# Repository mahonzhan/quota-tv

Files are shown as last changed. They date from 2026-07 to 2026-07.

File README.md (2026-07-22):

# QuotaTV — Claude + ChatGPT 订阅额度桌面显示器

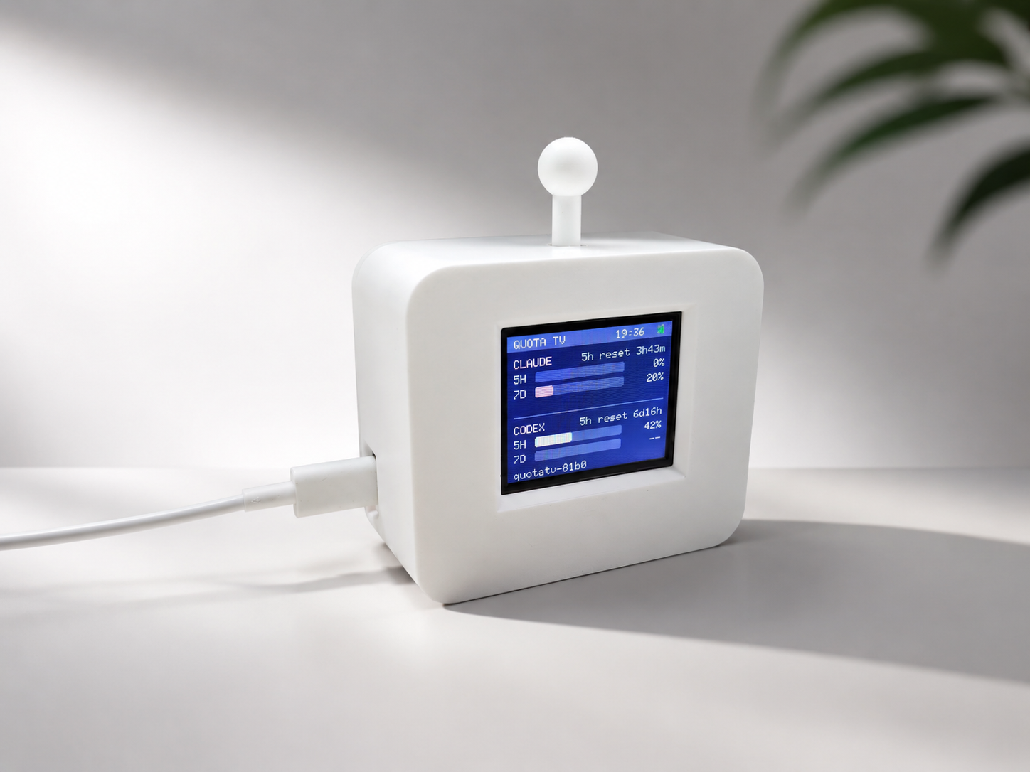
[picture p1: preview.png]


ESP32-C3 DevKitM-1 + 1.8" ST7735 的复古小电脑,单屏显示 Claude Code 与 ChatGPT(Codex) 的 5h/周额度使用率和重置倒计时,额度重置时蜂鸣提醒。设备直连两家接口,**不需要电脑常驻脚本**。

```
┌──────────────────────────────┐
│ QUOTA TV          14:32  ●   │
│ CLAUDE        5h reset 2h14m │
│  5H ██████████░░░░░░░   62%  │
│  7D ██████░░░░░░░░░░░   41%  │
│ ──────────────────────────── │
│ CODEX         5h reset 4h02m │
│  5H █████░░░░░░░░░░░░   30%  │
│  7D ████████████░░░░░   71%  │
│ 192.168.1.23                 │
└──────────────────────────────┘
```

## 1. 硬件与接线

| ST7735 屏 (8针) | ESP32-C3 DevKitM-1 |
|---|---|
| GND | GND |
| VCC | 3V3 |
| SCL / SCK | GPIO4 |
| SDA / MOSI | GPIO6 |
| RES / RST | GPIO10 |
| DC / A0 | GPIO5 |
| CS | GPIO7 |
| BLK / LED | GPIO3 |

| 蜂鸣器模块 (低电平触发) | DevKitM-1 |
|---|---|
| VCC | 3V3 (响声小可接 5V/VUSB) |
| GND | GND |
| I/O | GPIO1 |

> 避开了 C3 的 strapping 引脚 (GPIO2/8/9)。GPIO9 是板载 BOOT 键,固件里用作按钮。

## 2. 刷固件

```bash
pip install platformio
cd firmware
pio run -t upload        # USB 连接 DevKitM-1
pio device monitor       # 看日志 (115200)
```

### ST7735 变体调试(几乎必经步骤)

1.8" ST7735 有红标/绿标/黑标多种批次。本项目实测的蓝板 (丝印 1.8'TFT128*RGB*160) 为 **REDTAB + TFT_RGB**,已设为默认。其他批次若画面异常,改 `platformio.ini`:

- 偏移/花屏 → 把 `ST7735_REDTAB` 依次换成 `ST7735_BLACKTAB` / `ST7735_GREENTAB` / `ST7735_GREENTAB2` / `ST7735_GREENTAB3`
- 蓝橙互换 → `TFT_RGB_ORDER` 在 `TFT_RGB` / `TFT_BGR` 之间切换
- 方向反了 → `main.cpp` 里 `tft.setRotation(3)` 改成 `1`

## 3. 获取凭据

在装有 Claude Code 和 Codex CLI 的电脑上:

```bash
# Claude: 生成长期 OAuth token (推荐)
claude setup-token        # 输出 sk-ant-oat01-...

# Codex: 一键打印 access/refresh token
python tools/get_tokens.py
```

## 4. 配置设备

1. 首次上电自动进入配置模式;已配置的设备**运行中长按 BOOT 3 秒**(听到一声蜂鸣后松手)或 `curl -X POST http://<设备IP>/portal` 重新进入。注意**不要按住 BOOT 上电**——C3 会进串口下载模式导致黑屏(拔电重插即恢复)
2. 手机/电脑连接 `QuotaTV-xxxx` 热点,打开 `http://192.168.4.1`
3. 填 WiFi(2.4GHz)、Claude token、Codex access + refresh token,保存重启

运行后设备每 2 分钟刷新一次;按一下 BOOT 键立即刷新。浏览器访问 `http://<设备IP>/status` 可看 JSON 数据;`POST /reset` 清空配置。

## 5. 双工作模式

配置页可选两种模式:

**直连模式(默认)**:设备自己调两家接口,不依赖电脑。需在配置页填入 token。

**主机 Agent 模式**:token 不上设备,由电脑上的 `quota-agent`(Go 编写,单二进制零依赖)读取本机 Claude Code / Codex CLI 凭据,拉取额度后经局域网 HTTP 推送到设备(`POST /push`)。Codex token 由 CLI 自动续期,Agent 直接受益。代价是电脑关机后设备显示 stale。

### 设备发现(Agent 模式)

三层机制,按优先级:

1. **UDP 广播发现(主路径,不依赖 mDNS)**:Agent 向 18324 端口广播 `QUOTATV_DISCOVER?`,设备回 `{name, ip, mode}`。同网多台设备各有唯一名 `quotatv-xxxx`(MAC 后缀,屏幕底行与 IP 交替显示):发现多台时用 `-name quotatv-a1b2` 指定,或 `-all` 全部推送(数据只拉一次)
2. mDNS 兜底:每台设备注册 `quotatv-xxxx.local`
3. 手动指定:`-device http://192.168.x.x`(AP 隔离等广播不通的网络用这个)

### Agent 获取与运行

**推荐**:直接从 [Releases](https://github.com/mahonzhan/quota-tv/releases) 下载对应平台的 quota-agent(打 tag 后由 GitHub Actions 自动构建:Windows amd64 / macOS arm64+amd64 / Linux amd64)。

双击(或命令行)运行后**驻留系统托盘**(Windows 任务栏 / macOS 菜单栏 / Linux 状态区),托盘菜单提供:最近推送状态、立即推送、**开机自启开关**(写入各平台原生自启机制:注册表 Run / LaunchAgent / autostart desktop)、退出。

托盘直接显示额度:**macOS** 菜单栏图标旁显示文字 `C62/41 G30/71`(Claude/Codex 的 5h/7d 已用%);**Windows/Linux** 托盘不支持文字,数字直接渲染进图标——上行橙色为 Claude 5h、下行白色为 Codex 5h,悬停 tooltip 看完整数据。

**macOS 下载 `.app.zip`**(而非裸二进制):解压后双击即驻留菜单栏,不开终端、不占 Dock。首次打开因未签名会被 Gatekeeper 拦截,右键 → 打开 → 再点打开即可。裸二进制版供命令行/launchd 场景使用。

命令行参数(托盘模式同样生效):

```bash
quota-agent                  # 托盘常驻, 自动发现设备, 每 2 分钟推送
quota-agent -once            # 调试: 发现设备并推一次后退出
quota-agent -nogui           # 无托盘纯命令行 (服务器/systemd 场景)
quota-agent -name quotatv-a1b2   # 多设备时指定
quota-agent -all             # 多设备全部推送
quota-agent -device http://192.168.1.50   # 广播不通时手动指定
```

自己编译(`cd tools/quota-agent`):

```bash
# Windows — 必须加 -H windowsgui, 否则 exe 启动会弹黑色控制台窗口
go build -ldflags "-s -w -H windowsgui" -o quota-agent.exe

# macOS / Linux
go build -ldflags "-s -w" -o quota-agent
```

注意:`-H windowsgui` 的 GUI 版没有控制台,`log` 输出不可见;Windows 上调试(看发现/推送日志)时用不带该参数的构建跑 `quota-agent -once`。macOS 版依赖 cgo,需在 mac 上编译(Releases 里的由 CI 的 macos runner 构建)。

exe 文件图标:仓库已提交 `rsrc_windows_amd64.syso`(由 `icon.ico` 经 [akavel/rsrc](https://github.com/akavel/rsrc) 生成),`go build` 自动链接,无需额外操作;改图标时重新生成该文件即可(`go run github.com/akavel/rsrc@latest -ico icon.ico -o rsrc_windows_amd64.syso`)。macOS 裸二进制没有文件图标概念,要图标需打包成 .app bundle(未做,菜单栏图标不受影响)。

### 发布流程 (维护者)

```bash
git tag v1.0.0 && git push origin v1.0.0
```

`.github/workflows/release.yml` 会在三平台 runner 上构建 4 个二进制并自动创建 GitHub Release。

## 6. 数据来源(与风险)

- **Claude**:发送 `max_tokens=1` 的最小请求,从响应头 `anthropic-ratelimit-unified-5h/7d-utilization`(0~1)和 `-reset`(epoch)读取。每次探测消耗几个 token,量级可忽略。
- **Codex**:`GET chatgpt.com/backend-api/wham/usage`,零消耗;access token 过期时自动用 refresh token 到 `auth.openai.com` 续期并存入 NVS。
- 两个都是**非官方接口**,可能随时变化。解析已尽量写得宽容,失败时屏幕显示错误码,串口有原始响应片段可排查。
- 若设备端 refresh 与电脑上 Codex CLI 的凭据互相顶掉(表现为某一边频繁要求重新登录),改为定期从电脑重新粘贴 access token、refresh token 留空。
- 固件对 TLS 用 `setInsecure()`(不校验证书链)。家庭内网风险可接受;介意的话把各域名根证书写进固件。

## 6. 蜂鸣逻辑

- 任一窗口利用率相比上次骤降 ≥25 个百分点,或跨过 reset 时间点 → 蜂鸣(Claude 两声,Codex 三声)
- 静音时段 23:00–08:00(`config.h` 可改)
- 开机就绪一声短鸣

## 7. 外壳打印 (case/) — Claude bot 橙色机器人造型

用**橙色 PLA**打印(Claude 品牌色约 #D97757),效果图见 `case/assembly_preview.png`。

适配硬件:1.8" TFT128×RGB×160 蓝板屏 + **合宙 Core-ESP32C3** + 三针立式有源蜂鸣器模块,飞线直焊。

- `body.stl` — 机器人头主壳(74×64×30, 大圆角):前脸朝下打印,免支撑;顶部天线插孔,右侧壁后缘 USB-C 出线缺口
- `antenna.stl` — 球头天线:竖直打印,杆 φ5.6 插入 φ6 孔,过松点胶
- `back.stl` — 后盖:平放打印;含 **BOOT/RST 两个按钮孔**、蜂鸣孔、散热缝、唇部 USB 缺口
- `button_plunger_x2.stl` — 按钮顶杆,打印 2 个:蘑菇头朝内放入孔中,再贴板,即可从壳外按 BOOT/RST
- `stand.stl` — 12° 仰角底座,带两只小脚趾
- 装配:屏幕贴入前脸内侧定位框 → 顶杆入孔 → **合宙板元件面朝后盖**、USB-C 对准 -x 缺口方向,按钮对准顶杆后用双面胶/热熔胶贴在后盖内侧 → 蜂鸣器贴出音孔附近 → 飞线焊好插上后盖 → 插天线 → 卡入底座
- 源文件 `gen_case.py`(STL 以它为准):打印前量三个尺寸并改参数重新生成——屏模块 PCB 宽高(`SCR_PCB_W/H`)、合宙板 USB 端边缘到按钮中心距(`BTN_FROM_USB`)、两按钮中心距(`BTN_GAP`)

## 8. 安全提醒

token 等同账号使用权,只存在设备 NVS 里,不要把配置好的设备借人;闲鱼出手前 `POST /reset` 或重刷固件。

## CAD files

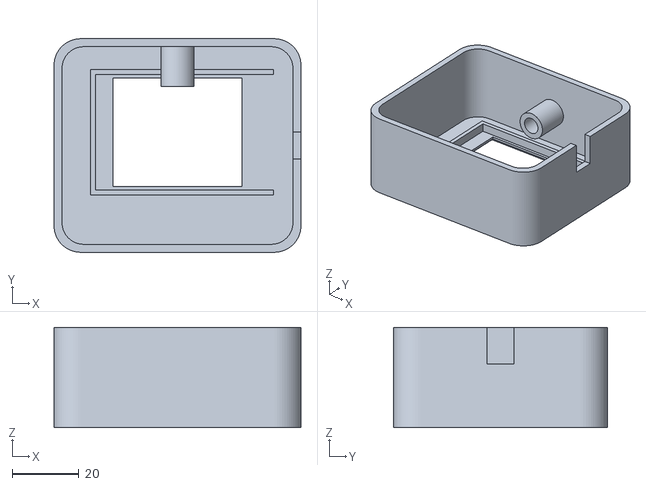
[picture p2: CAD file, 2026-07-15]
case/body.stl
74.0 x 64.0 x 30.0

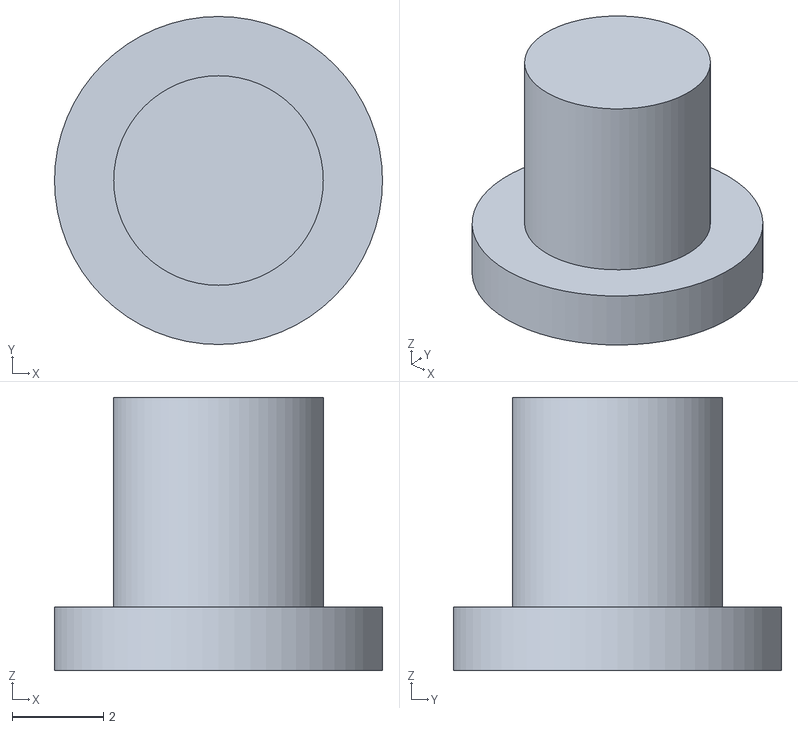
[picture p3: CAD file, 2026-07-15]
case/button_plunger_x2.stl
7.20 x 7.20 x 6.00

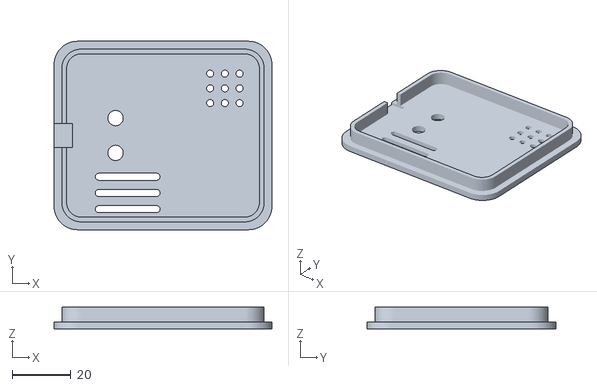
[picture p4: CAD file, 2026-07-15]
case/back.stl
74.0 x 64.0 x 7.40

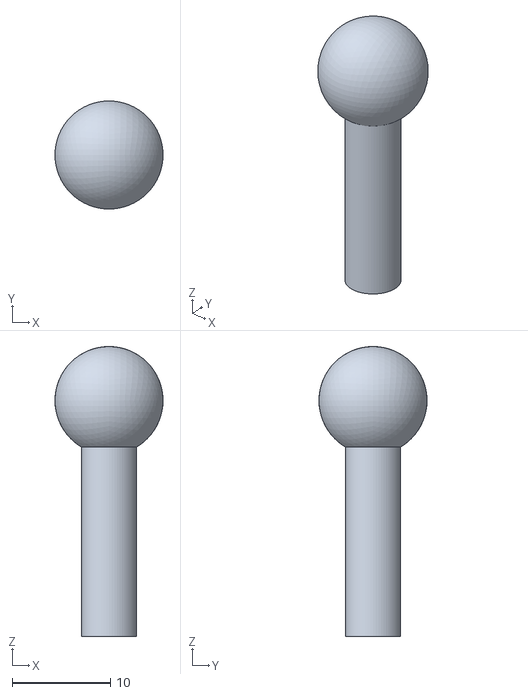
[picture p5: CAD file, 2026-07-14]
case/antenna.stl
11.0 x 11.0 x 29.5

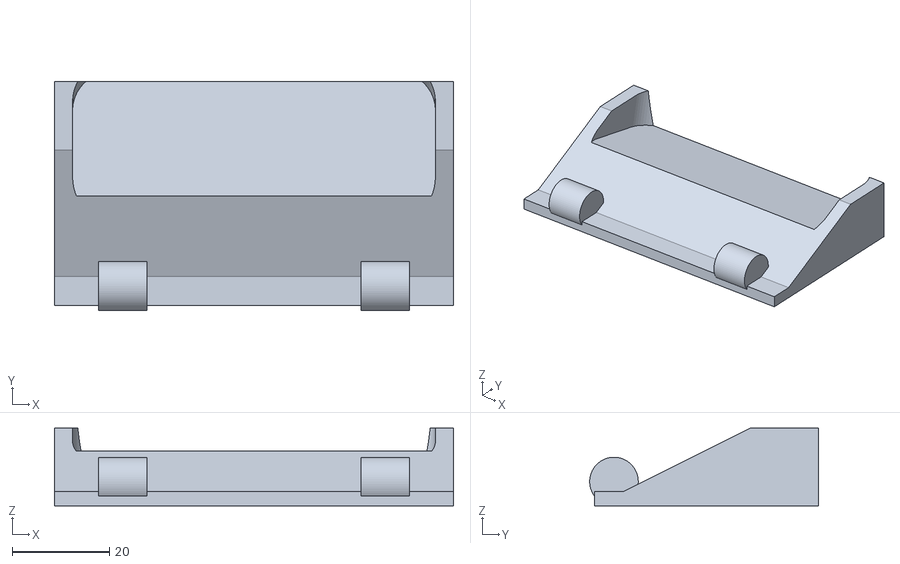
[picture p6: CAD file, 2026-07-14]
case/stand.stl
82.0 x 47.0 x 16.0

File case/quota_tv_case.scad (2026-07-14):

// ============================================================
// QuotaTV 外壳 — Claude bot 橙色机器人造型 (参数化, 与 gen_case.py 等价)
// 部件: body / back / antenna / stand    橙色 PLA (#D97757)
// 注意: 发货 STL 由 gen_case.py 生成; 本文件供 OpenSCAD 用户改参
// ============================================================

part = "all"; // [all, body, back, antenna, stand]

/* ---- 屏幕 1.8" ST7735 ---- */
scr_view_w = 36.5;  scr_view_h = 29.5;   // 可视区开窗
scr_pcb_w  = 58;    scr_pcb_h  = 35;     // 模块 PCB, 按实物量!
scr_y_off  = 4;

/* ---- 主体 ---- */
wall = 2.4;
body_w = 74; body_h = 64; body_d = 30;
corner = 8;                              // 大圆角机器人头

/* ---- 后盖 ---- */
lip_d = 5; lip_clear = 0.28;
usb_w = 13; usb_h = 8; usb_z = 10;

/* ---- 天线 ---- */
ant_hole_d = 6; ant_stem_d = 5.6;
ant_stem_h = 16; ant_ball_d = 11;

/* ---- 底座 ---- */
tilt = 12; stand_d = 46; stand_lip = 7;

$fn = 64;

module rbox(w, h, d, r) {
  translate([w/2, h/2, 0]) linear_extrude(d) offset(r = r) square([w - 2*r, h - 2*r], center = true);
}

module body() {
  difference() {
    union() {
      difference() {
        rbox(body_w, body_h, body_d, corner);
        translate([wall, wall, wall]) rbox(body_w - 2*wall, body_h - 2*wall, body_d, corner - 1.5);
      }
      // 天线凸台
      translate([body_w/2, body_h - wall + 0.01, body_d/2])
        rotate([90, 0, 0]) cylinder(h = 12, d = 10);
      // 屏幕定位框
      translate([body_w/2, body_h/2 + scr_y_off, wall]) difference() {
        translate([-scr_pcb_w/2 - 1.8, -scr_pcb_h/2 - 1.8, 0]) cube([scr_pcb_w + 3.6, scr_pcb_h + 3.6, 3]);
        translate([-scr_pcb_w/2 - 0.3, -scr_pcb_h/2 - 0.3, -0.5]) cube([scr_pcb_w + 0.6, scr_pcb_h + 0.6, 4]);
      }
    }
    // 屏幕开窗 + 外侧倒角
    translate([body_w/2, body_h/2 + scr_y_off, 0]) {
      translate([-scr_view_w/2, -scr_view_h/2, -0.5]) cube([scr_view_w, scr_view_h, wall + 1]);
      hull() {
        translate([-scr_view_w/2 - 1.6, -scr_view_h/2 - 1.6, -0.5]) cube([scr_view_w + 3.2, scr_view_h + 3.2, 0.5]);
        translate([-scr_view_w/2, -scr_view_h/2, wall - 0.8]) cube([scr_view_w, scr_view_h, 0.1]);
      }
    }
    // 天线通孔
    translate([body_w/2, body_h + 0.01, body_d/2]) rotate([90, 0, 0]) cylinder(h = wall + 12.5, d = ant_hole_d);
  }
}

module back() {
  difference() {
    union() {
      rbox(body_w, body_h, wall, corner);
      translate([wall + lip_clear, wall + lip_clear, wall]) difference() {
        rbox(body_w - 2*wall - 2*lip_clear, body_h - 2*wall - 2*lip_clear, lip_d, corner - 1.5);
        translate([1.6, 1.6, -0.5])
          rbox(body_w - 2*wall - 2*lip_clear - 3.2, body_h - 2*wall - 2*lip_clear - 3.2, lip_d + 1, corner - 3);
      }
    }
    translate([body_w/2 - usb_w/2, usb_z - usb_h/2, -0.5]) cube([usb_w, usb_h, wall + lip_d + 1]);
    for (dx = [-5, 0, 5], dy = [-5, 0, 5])
      translate([body_w - 16 + dx, body_h - 16 + dy, -0.5]) cylinder(h = wall + 2, d = 2.4);
    for (i = [0:3]) translate([14, body_h/2 - 8 + i*7, -0.5]) rbox(22, 2.4, wall + 2, 1.2);
  }
}

module antenna() {
  cylinder(h = 8 + ant_stem_h, d = ant_stem_d);
  translate([0, 0, 8 + ant_stem_h]) sphere(d = ant_ball_d);
}

module stand() {
  w = body_w + 8;
  difference() {
    translate([w, 0, 0]) rotate([0, -90, 0]) linear_extrude(w)
      polygon([[0,0],[3,0],[3,6],[16,stand_d-14],[16,stand_d],[0,stand_d]]); // (z,y) 轮廓
    // 主体卡槽
    translate([w/2 - 4, stand_d - 13, 16 - stand_lip]) rotate([-tilt, 0, 0])
      translate([-(body_w/2 + lip_clear) + 4, -(body_d/2 + lip_clear), 0])
        rbox(body_w + 2*lip_clear, body_d + 2*lip_clear, body_h, corner);
  }
  for (sx = [14, w - 14]) translate([sx - 5, 4, 5]) rotate([0, 90, 0]) cylinder(h = 10, r = 5);
}

if (part == "body"    || part == "all") body();
if (part == "back"    || part == "all") translate([body_w + 12, 0, 0]) back();
if (part == "antenna" || part == "all") translate([-16, 20, 0]) antenna();
if (part == "stand"   || part == "all") translate([0, body_h + 14, 0]) stand();

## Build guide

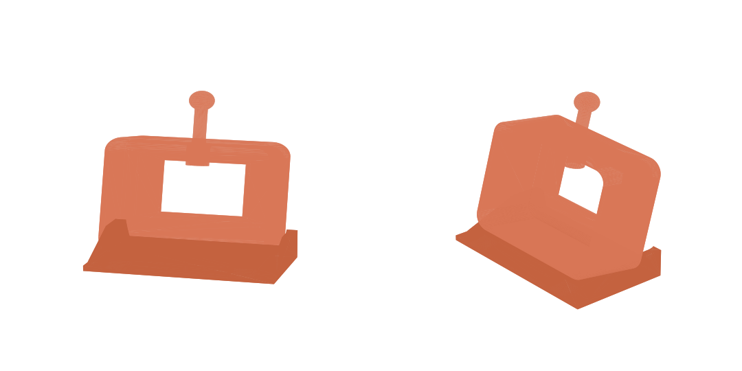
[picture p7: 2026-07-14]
case/assembly_preview.png

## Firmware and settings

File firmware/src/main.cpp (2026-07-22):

// ============================================================
// QuotaTV — Claude Code + ChatGPT(Codex) 订阅额度桌面显示器
// 硬件: ESP32-C3 DevKitM-1 + 1.8" ST7735 (128x160) + 低电平有源蜂鸣器
// 功能: 单屏显示两家 5h/周额度利用率 + 重置倒计时, 额度重置时蜂鸣提醒
// ============================================================

#include <Arduino.h>
#include <WiFi.h>
#include <WiFiClientSecure.h>
#include <HTTPClient.h>
#include <WebServer.h>
#include <DNSServer.h>
#include <ESPmDNS.h>
#include <WiFiUdp.h>
#include <Preferences.h>
#include <ArduinoJson.h>
#include <TFT_eSPI.h>
#include <time.h>
#include "config.h"

// ---------------- 全局 ----------------
TFT_eSPI    tft;
TFT_eSprite canvas(&tft);          // 全屏离屏缓冲, 防闪烁 (160x128x2 = 40KB)
Preferences prefs;
WebServer   server(80);
DNSServer   dns;
WiFiUDP     udp;                   // UDP 发现响应 (不依赖 mDNS)
String      devName;               // quotatv-xxxx (MAC 后缀, 全网唯一)
#define DISCOVERY_PORT 18324

struct Cfg {
  String ssid, pass;
  String mode;                     // "direct" 直连 (默认) / "agent" 主机推送
  String claudeToken;              // sk-ant-oat01-... (claude setup-token)
  String codexAccess, codexRefresh;
} cfg;

struct WindowData {
  float  usedPct    = -1;          // 0~100, <0 = 无数据
  time_t resetAt    = 0;           // unix epoch, 0 = 未知
};
uint32_t staleAfterMs = STALE_AFTER_MS;   // agent 模式下由推送帧 interval 动态覆盖
struct ProviderData {
  WindowData session, weekly;      // 5h / 7d
  uint32_t lastOkMs   = 0;
  String   lastErr;
  bool fresh() const { return lastOkMs && (millis() - lastOkMs) < staleAfterMs; }
  uint32_t ageMin() const { return lastOkMs ? (millis() - lastOkMs) / 60000UL : 0; }
};
ProviderData claudeData, codexData;

bool portalMode = false;
uint32_t lastPollMs = 0;
bool firstPollDone = false;

// ---------------- 颜色 ----------------
#define C_BG        0x0000                       // 黑
#define C_HEADER    0x39C7                       // 深灰
#define C_TEXT      0xEF7D                       // 近白
#define C_DIM       0x8410                       // 中灰
#define C_CLAUDE    0xD3AB                       // Claude 品牌橙红 #D97757 精确转换
#define C_CODEX     0xFFFF                       // Codex 白
#define C_BAR_BG    0x2124                       // bar 底槽
#define C_WARN      0xFDA0                       // 黄
#define C_DANGER    0xF9E7                       // 红

// ============================================================
// 蜂鸣器 (低电平触发)
// ============================================================
static void buzzInit() {
  pinMode(PIN_BUZZER, OUTPUT);
  digitalWrite(PIN_BUZZER, HIGH);  // 立刻拉高静音
}
static bool inQuietHours() {
  struct tm t;
  if (!getLocalTime(&t, 50)) return false;
  int h = t.tm_hour;
  if (QUIET_HOUR_START > QUIET_HOUR_END)       // 跨午夜, 如 23~8
    return h >= QUIET_HOUR_START || h < QUIET_HOUR_END;
  return h >= QUIET_HOUR_START && h < QUIET_HOUR_END;
}
static void beep(uint8_t n, uint16_t onMs = 90, uint16_t offMs = 90) {
  for (uint8_t i = 0; i < n; i++) {
    digitalWrite(PIN_BUZZER, LOW);  delay(onMs);
    digitalWrite(PIN_BUZZER, HIGH); delay(offMs);
  }
}

// ============================================================
// 小工具
// ============================================================
static String fmtCountdown(time_t resetAt) {
  time_t now = time(nullptr);
  if (resetAt <= 0 || now < 1600000000 || resetAt <= now) return "";
  long s = resetAt - now;
  char buf[16];
  if (s >= 86400)      snprintf(buf, sizeof(buf), "%ldd%02ldh", s / 86400, (s % 86400) / 3600);
  else if (s >= 3600)  snprintf(buf, sizeof(buf), "%ldh%02ldm", s / 3600, (s % 3600) / 60);
  else                 snprintf(buf, sizeof(buf), "%ldm", s / 60);
  return String(buf);
}

// base64url 解码 (用于解析 JWT exp)
static String b64urlDecode(const String& in) {
  String s = in;
  s.replace('-', '+'); s.replace('_', '/');
  while (s.length() % 4) s += '=';
  static const char* T = "ABCDEFGHIJKLMNOPQRSTUVWXYZabcdefghijklmnopqrstuvwxyz0123456789+/";
  String out; out.reserve(s.length() * 3 / 4);
  int val = 0, bits = 0;
  for (size_t i = 0; i < s.length(); i++) {
    char c = s[i];
    if (c == '=') break;
    const char* p = strchr(T, c);
    if (!p) continue;
    val = (val << 6) | (p - T);
    bits += 6;
    if (bits >= 8) { bits -= 8; out += (char)((val >> bits) & 0xFF); }
  }
  return out;
}
static time_t jwtExp(const String& jwt) {
  int p1 = jwt.indexOf('.'), p2 = jwt.indexOf('.', p1 + 1);
  if (p1 < 0 || p2 < 0) return 0;
  String payload = b64urlDecode(jwt.substring(p1 + 1, p2));
  JsonDocument doc;
  if (deserializeJson(doc, payload)) return 0;
  return (time_t)(doc["exp"] | 0UL);
}

// ============================================================
// 重置检测 + 蜂鸣
// ============================================================
static void checkReset(const char* name, WindowData& prev, const WindowData& fresh_, uint8_t beeps) {
  bool wasValid = prev.usedPct >= 0;
  bool dropped  = wasValid && fresh_.usedPct >= 0 &&
                  (prev.usedPct - fresh_.usedPct) >= RESET_DROP_THRESHOLD;
  bool resetPassed = prev.resetAt > 0 && fresh_.resetAt > prev.resetAt &&
                     time(nullptr) >= prev.resetAt && wasValid && prev.usedPct >= 20;
  if (dropped || resetPassed) {
    Serial.printf("[beep] %s reset: %.0f%% -> %.0f%%\n", name, prev.usedPct, fresh_.usedPct);
    if (!inQuietHours()) beep(beeps);
  }
}

// ============================================================
// Claude: 最小请求, 读 anthropic-ratelimit-unified-* 响应头
// ============================================================
static bool fetchClaude() {
  if (cfg.claudeToken.isEmpty()) { claudeData.lastErr = "no token"; return false; }
  WiFiClientSecure client;
  client.setInsecure();                      // 简化: 不校验证书 (README 有说明)
  HTTPClient http;
  http.setTimeout(HTTP_TIMEOUT_MS);
  if (!http.begin(client, String("https://") + CLAUDE_API_HOST + CLAUDE_API_PATH)) {
    claudeData.lastErr = "begin fail"; return false;
  }
  const char* keys[] = {
    "anthropic-ratelimit-unified-5h-utilization",
    "anthropic-ratelimit-unified-7d-utilization",
    "anthropic-ratelimit-unified-5h-reset",
    "anthropic-ratelimit-unified-7d-reset",
  };
  http.collectHeaders(keys, 4);
  http.addHeader("Content-Type", "application/json");
  http.addHeader("Authorization", "Bearer " + cfg.claudeToken);
  http.addHeader("anthropic-version", "2023-06-01");
  http.addHeader("anthropic-beta", "oauth-2025-04-20");
  String body = String("{\"model\":\"") + CLAUDE_PROBE_MODEL +
                "\",\"max_tokens\":1,\"messages\":[{\"role\":\"user\",\"content\":\"hi\"}]}";
  int code = http.POST(body);
  String u5 = http.header(keys[0]), u7 = http.header(keys[1]);
  String r5 = http.header(keys[2]), r7 = http.header(keys[3]);
  http.end();

  if (u5.isEmpty() && u7.isEmpty()) {
    claudeData.lastErr = "HTTP " + String(code);
    Serial.printf("[claude] no ratelimit headers, code=%d\n", code);
    return false;
  }
  WindowData s, w;
  if (!u5.isEmpty()) s.usedPct = u5.toFloat() * 100.0f;
  if (!u7.isEmpty()) w.usedPct = u7.toFloat() * 100.0f;
  // reset 头可能是 unix epoch 或 RFC3339, 只处理纯数字情况
  if (r5.length() && r5[0] >= '0' && r5[0] <= '9' && r5.indexOf('-') < 0) s.resetAt = (time_t)strtoul(r5.c_str(), nullptr, 10);
  if (r7.length() && r7[0] >= '0' && r7[0] <= '9' && r7.indexOf('-') < 0) w.resetAt = (time_t)strtoul(r7.c_str(), nullptr, 10);

  checkReset("claude-5h", claudeData.session, s, 2);
  checkReset("claude-7d", claudeData.weekly,  w, 2);
  claudeData.session = s; claudeData.weekly = w;
  claudeData.lastOkMs = millis(); claudeData.lastErr = "";
  Serial.printf("[claude] 5h=%.1f%% 7d=%.1f%%\n", s.usedPct, w.usedPct);
  return true;
}

// ============================================================
// Codex: GET wham/usage, 必要时用 refresh token 刷新
// ============================================================
static bool codexRefreshToken() {
  if (cfg.codexRefresh.isEmpty()) return false;
  WiFiClientSecure client; client.setInsecure();
  HTTPClient http;
  http.setTimeout(HTTP_TIMEOUT_MS);
  if (!http.begin(client, OPENAI_TOKEN_URL)) return false;
  http.addHeader("Content-Type", "application/json");
  JsonDocument req;
  req["client_id"]     = CODEX_CLIENT_ID;
  req["grant_type"]    = "refresh_token";
  req["refresh_token"] = cfg.codexRefresh;
  req["scope"]         = "openid profile email";
  String body; serializeJson(req, body);
  int code = http.POST(body);
  if (code != 200) { http.end(); Serial.printf("[codex] refresh fail %d\n", code); return false; }
  JsonDocument doc;
  DeserializationError e = deserializeJson(doc, http.getStream());
  http.end();
  if (e) return false;
  const char* at = doc["access_token"];
  const char* rt = doc["refresh_token"];
  if (!at) return false;
  cfg.codexAccess = at;
  if (rt && strlen(rt)) cfg.codexRefresh = rt;
  prefs.begin("quotatv", false);
  prefs.putString("cx_at", cfg.codexAccess);
  prefs.putString("cx_rt", cfg.codexRefresh);
  prefs.end();
  Serial.println("[codex] token refreshed");
  return true;
}

// 从 wham/usage 的 window 对象里尽量兼容地取值
static void parseCodexWindow(JsonVariantConst w, WindowData& out) {
  if (w.isNull()) return;
  if (w["used_percent"].is<float>())        out.usedPct = w["used_percent"].as<float>();
  else if (w["usage_percent"].is<float>())  out.usedPct = w["usage_percent"].as<float>();
  else if (w["used"].is<float>())           out.usedPct = w["used"].as<float>();
  time_t now = time(nullptr);
  if (w["resets_at"].is<long long>())            out.resetAt = (time_t)w["resets_at"].as<long long>();
  else if (w["reset_at"].is<long long>())        out.resetAt = (time_t)w["reset_at"].as<long long>();
  else if (w["resets_in_seconds"].is<long>())    out.resetAt = now + w["resets_in_seconds"].as<long>();
  else if (w["reset_after_seconds"].is<long>())  out.resetAt = now + w["reset_after_seconds"].as<long>();
  if (out.resetAt > 4102444800LL) out.resetAt /= 1000;   // 毫秒时间戳兜底
}

static bool fetchCodex() {
  if (cfg.codexAccess.isEmpty()) { codexData.lastErr = "no token"; return false; }
  // 到期前主动刷新
  time_t exp = jwtExp(cfg.codexAccess);
  time_t now = time(nullptr);
  if (exp > 0 && now > 1600000000 && exp - now < (time_t)CODEX_REFRESH_MARGIN_S) codexRefreshToken();

  for (int attempt = 0; attempt < 2; attempt++) {
    WiFiClientSecure client; client.setInsecure();
    HTTPClient http;
    http.setTimeout(HTTP_TIMEOUT_MS);
    if (!http.begin(client, CODEX_USAGE_URL)) { codexData.lastErr = "begin fail"; return false; }
    http.addHeader("Authorization", "Bearer " + cfg.codexAccess);
    http.addHeader("Accept", "application/json");
    http.addHeader("User-Agent", "QuotaTV/1.0");
    int code = http.GET();
    if (code == 401 && attempt == 0) {           // 过期 → 刷新重试
      http.end();
      if (!codexRefreshToken()) { codexData.lastErr = "401 refresh fail"; return false; }
      continue;
    }
    if (code != 200) { http.end(); codexData.lastErr = "HTTP " + String(code); return false; }
    JsonDocument doc;
    DeserializationError e = deserializeJson(doc, http.getStream());
    http.end();
    if (e) { codexData.lastErr = "json err"; return false; }

    JsonVariantConst rl = doc["rate_limit"];
    if (rl.isNull()) rl = doc["rate_limits"];
    WindowData s, w;
    parseCodexWindow(rl["primary_window"],   s);
    parseCodexWindow(rl["secondary_window"], w);
    if (s.usedPct < 0 && w.usedPct < 0) {
      // 结构不认识: 打印首 300 字符方便排查
      String dump; serializeJson(doc, dump);
      Serial.println("[codex] unknown shape: " + dump.substring(0, 300));
      codexData.lastErr = "parse shape";
      return false;
    }
    checkReset("codex-5h", codexData.session, s, 3);
    checkReset("codex-7d", codexData.weekly,  w, 3);
    codexData.session = s; codexData.weekly = w;
    codexData.lastOkMs = millis(); codexData.lastErr = "";
    Serial.printf("[codex] 5h=%.1f%% 7d=%.1f%%\n", s.usedPct, w.usedPct);
    return true;
  }
  return false;
}

// ============================================================
// UI (160x128 横屏)
// ============================================================
static uint16_t barColor(float pct) {
  if (pct >= 90) return C_DANGER;
  if (pct >= 70) return C_WARN;
  return C_TEXT;
}

static void drawBarRow(int y, const char* label, const WindowData& w, uint16_t accent) {
  canvas.setTextFont(1);
  canvas.setTextColor(C_DIM, C_BG);
  canvas.setTextDatum(TL_DATUM);
  canvas.drawString(label, 6, y + 1);

  const int bx = 26, bw = 86, bh = 9;
  canvas.fillRoundRect(bx, y, bw, bh, 2, C_BAR_BG);
  if (w.usedPct >= 0) {
    int fw = (int)(bw * constrain(w.usedPct, 0.0f, 100.0f) / 100.0f);
    if (fw > 0) canvas.fillRoundRect(bx, y, max(fw, 3), bh, 2, accent);
    // 百分比 (整组已变灰时百分比也灰)
    canvas.setTextColor(accent == C_DIM ? C_DIM : barColor(w.usedPct), C_BG);
    canvas.setTextDatum(TR_DATUM);
    canvas.drawString(String((int)(w.usedPct + 0.5f)) + "%", 154, y + 1);
  } else {
    canvas.setTextColor(C_DIM, C_BG);
    canvas.setTextDatum(TR_DATUM);
    canvas.drawString("--", 154, y + 1);
  }
}

static void drawProvider(int y, const char* name, uint16_t accent, const ProviderData& d) {
  bool stale = !d.fresh();
  uint16_t ac = stale ? C_DIM : accent;      // stale: 整组变灰
  canvas.setTextFont(1);
  canvas.setTextDatum(TL_DATUM);
  canvas.setTextColor(ac, C_BG);
  canvas.drawString(name, 6, y);
  // 右侧: stale 时显示距上次成功多久, 否则显示倒计时
  String cd = fmtCountdown(d.session.resetAt);
  canvas.setTextColor(stale ? C_WARN : C_DIM, C_BG);
  canvas.setTextDatum(TR_DATUM);
  if (stale) {
    String msg = d.lastOkMs ? ("stale " + String(d.ageMin()) + "m")
                            : (d.lastErr.length() ? d.lastErr : "no data");
    canvas.drawString(msg, 154, y);
  } else if (cd.length()) {
    canvas.drawString("5h reset " + cd, 154, y);
  }
  drawBarRow(y + 12, "5H", d.session, ac);
  drawBarRow(y + 25, "7D", d.weekly,  ac);
}

static void drawScreen() {
  canvas.fillSprite(C_BG);
  // 头部
  canvas.fillRect(0, 0, 160, 13, C_HEADER);
  canvas.setTextFont(1);
  canvas.setTextDatum(TL_DATUM);
  canvas.setTextColor(C_TEXT, C_HEADER);
  canvas.drawString("QUOTA TV", 6, 3);
  struct tm t;
  if (getLocalTime(&t, 20)) {
    char hm[6]; snprintf(hm, sizeof(hm), "%02d:%02d", t.tm_hour, t.tm_min);
    canvas.setTextDatum(TR_DATUM);
    canvas.drawString(hm, 132, 3);
  }
  // WiFi 状态点
  canvas.fillCircle(148, 6, 3, WiFi.status() == WL_CONNECTED ? 0x07E0 : C_DANGER);

  drawProvider(20, "CLAUDE", C_CLAUDE, claudeData);
  canvas.drawFastHLine(6, 70, 148, C_HEADER);
  drawProvider(78, "CODEX", C_CODEX, codexData);

  // 底部状态行
  canvas.setTextDatum(BL_DATUM);
  canvas.setTextColor(C_DIM, C_BG);
  // 底行交替显示设备名和 IP (各 4 秒)
  bool showName = (millis() / 4000) % 2 == 0;
  String bottom = showName ? devName : WiFi.localIP().toString();
  if (cfg.mode == "agent" && !firstPollDone) bottom = devName + " wait push";
  else if (!firstPollDone) bottom = "loading...";
  canvas.drawString(bottom, 6, 127);
  canvas.pushSprite(0, 0);
}

static void drawMessage(const char* l1, const char* l2 = "", const char* l3 = "") {
  canvas.fillSprite(C_BG);
  canvas.setTextFont(1);
  canvas.setTextDatum(TL_DATUM);
  canvas.setTextColor(C_CLAUDE, C_BG); canvas.drawString("QUOTA TV", 6, 6);
  canvas.setTextColor(C_TEXT, C_BG);
  canvas.drawString(l1, 6, 34);
  canvas.drawString(l2, 6, 50);
  canvas.setTextColor(C_DIM, C_BG);
  canvas.drawString(l3, 6, 66);
  canvas.pushSprite(0, 0);
}

// ============================================================
// 配置门户 (AP + captive portal)
// ============================================================
static const char PORTAL_HTML[] PROGMEM = R"html(<!DOCTYPE html>
<html><head><meta charset="utf-8"><meta name="viewport" content="width=device-width,initial-scale=1">
<title>QuotaTV Setup</title><style>
body{font-family:sans-serif;max-width:480px;margin:20px auto;padding:0 14px;background:#111;color:#eee}
h2{color:#D97757}label{display:block;margin:12px 0 4px;font-size:14px;color:#aaa}
input,textarea{width:100%;box-sizing:border-box;padding:8px;border-radius:6px;border:1px solid #444;background:#1c1c1c;color:#eee;font-size:13px}
textarea{height:64px}button{margin-top:18px;width:100%;padding:12px;border:0;border-radius:8px;background:#D97757;color:#fff;font-size:16px}
small{color:#777}</style></head><body>
<h2>QuotaTV 配置</h2>
<form method="POST" action="/save">
<label>WiFi 名称 (2.4GHz)</label><input name="ssid" required>
<label>WiFi 密码</label><input name="pass" type="password">
<label>工作模式</label>
<select name="mode" style="width:100%;padding:8px;border-radius:6px;border:1px solid #444;background:#1c1c1c;color:#eee">
<option value="direct">直连模式 — 设备自己拉数据 (需填下方 token)</option>
<option value="agent">主机 Agent 模式 — 电脑推送 (token 留空)</option>
</select>
<label>Claude OAuth Token <small>(终端运行 claude setup-token 获取, sk-ant-oat01-...)</small></label>
<textarea name="ctok"></textarea>
<label>Codex Access Token <small>(~/.codex/auth.json 的 tokens.access_token)</small></label>
<textarea name="cxat"></textarea>
<label>Codex Refresh Token <small>(tokens.refresh_token, 用于自动续期)</small></label>
<textarea name="cxrt"></textarea>
<button type="submit">保存并重启</button>
</form>
<p><small>Agent 模式: 到 github.com/mahonzhan/quota-tv/releases 下载对应平台的
quota-agent 桌面应用, 在电脑上常驻运行即可, 无需在此填 token。<br>
直连模式: 三个 token 可用仓库 tools/get_tokens.py 一键打印。</small></p>
</body></html>)html";

static void handleSave() {
  prefs.begin("quotatv", false);
  prefs.putString("ssid",  server.arg("ssid"));
  prefs.putString("pass",  server.arg("pass"));
  prefs.putString("mode",  server.arg("mode") == "agent" ? "agent" : "direct");
  if (server.arg("ctok").length()) prefs.putString("c_tok", server.arg("ctok"));
  if (server.arg("cxat").length()) prefs.putString("cx_at", server.arg("cxat"));
  if (server.arg("cxrt").length()) prefs.putString("cx_rt", server.arg("cxrt"));
  prefs.end();
  server.send(200, "text/html; charset=utf-8",
              "<h3>已保存, 设备重启中...</h3>");
  delay(800);
  ESP.restart();
}

static void startPortal() {
  portalMode = true;
  String apName = devName;
  WiFi.mode(WIFI_AP);
  WiFi.softAPConfig(AP_IP, AP_IP, IPAddress(255, 255, 255, 0));
  WiFi.softAP(apName.c_str());
  dns.start(53, "*", AP_IP);
  server.onNotFound([]() { server.send(200, "text/html; charset=utf-8", FPSTR(PORTAL_HTML)); });
  server.on("/save", HTTP_POST, handleSave);
  server.begin();
  drawMessage("Setup mode", ("WiFi: " + apName).c_str(), "open 192.168.4.1");
  Serial.printf("[portal] AP %s, http://192.168.4.1\n", apName.c_str());
}

// Agent 推送: 把 JSON 里的一个 provider 应用到数据结构
static void applyPush(JsonVariantConst v, ProviderData& d, const char* name, uint8_t beeps) {
  if (v.isNull()) return;
  WindowData s = d.session, w = d.weekly;
  if (v["session"].is<float>())      s.usedPct = v["session"].as<float>();
  if (v["weekly"].is<float>())       w.usedPct = v["weekly"].as<float>();
  if (v["sessionReset"].is<long long>()) s.resetAt = (time_t)v["sessionReset"].as<long long>();
  if (v["weeklyReset"].is<long long>())  w.resetAt = (time_t)v["weeklyReset"].as<long long>();
  checkReset((String(name) + "-5h").c_str(), d.session, s, beeps);
  checkReset((String(name) + "-7d").c_str(), d.weekly,  w, beeps);
  d.session = s; d.weekly = w;
  d.lastOkMs = millis(); d.lastErr = "";
}
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
void loop() {
  if (portalMode) { dns.processNextRequest(); server.handleClient(); return; }

  server.handleClient();

  // UDP 发现: 收到 "QUOTATV_DISCOVER" 即回自己的名字+IP
  if (udp.parsePacket() > 0) {
    char buf[40];
    int n = udp.read(buf, sizeof(buf) - 1);
    buf[n > 0 ? n : 0] = 0;
    if (strncmp(buf, "QUOTATV_DISCOVER", 16) == 0) {
      String r = "{\"name\":\"" + devName + "\",\"ip\":\"" +
                 WiFi.localIP().toString() + "\",\"mode\":\"" + cfg.mode + "\"}";
      udp.beginPacket(udp.remoteIP(), udp.remotePort());
      udp.print(r);
      udp.endPacket();
    }
  }

  uint32_t nowMs = millis();
  if (cfg.mode != "agent" &&
      (!firstPollDone || nowMs - lastPollMs >= POLL_INTERVAL_MS)) {
    lastPollMs = nowMs;
    fetchClaude();
    fetchCodex();
    firstPollDone = true;
    drawScreen();
  }

  // 每秒刷新一次 (时钟/倒计时)
  static uint32_t lastDraw = 0;
  if (nowMs - lastDraw >= 1000) { lastDraw = nowMs; drawScreen(); }

  // 运行中 BOOT 键: 短按=立即刷新, 长按 3 秒(蜂鸣)=重启进配置模式
  if (digitalRead(PIN_BOOT_BTN) == LOW) {
    uint32_t press = millis();
    bool longPress = false;
    while (digitalRead(PIN_BOOT_BTN) == LOW) {
      if (!longPress && millis() - press >= 3000) {
        longPress = true;
        beep(1, 250);                       // 提示: 可以松手了
      }
      delay(10);
    }
    if (longPress) {
      prefs.begin("quotatv", false);
      prefs.putBool("portal", true);
      prefs.end();
      ESP.restart();
    } else if (millis() - press >= 50) {
      lastPollMs = 0; firstPollDone = false; // 短按强制刷新
    }
  }
  delay(10);
}

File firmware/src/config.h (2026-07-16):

#pragma once

// ================= 引脚 (ESP32-C3 DevKitM-1) =================
// TFT SPI 引脚在 platformio.ini 的 build_flags 里 (SCLK=4 MOSI=6 CS=7 DC=5 RST=10)
#define PIN_TFT_BL     3    // 背光, PWM
#define PIN_BUZZER     1    // 有源蜂鸣器, 低电平触发
#define PIN_BOOT_BTN   9    // 板载 BOOT 键: 开机长按进入配置模式

// ================= 轮询 =================
#define POLL_INTERVAL_MS      (120UL * 1000UL)  // 每 2 分钟刷新一次额度
#define HTTP_TIMEOUT_MS       15000
// 超过 3 个轮询周期没有成功数据 → 标记 stale (进度条变灰)
// agent 模式下若推送帧带 interval 字段, 以 3x 该值动态覆盖
#define STALE_AFTER_MS        (3UL * POLL_INTERVAL_MS)

// ================= Claude =================
// 通过发送 max_tokens=1 的最小请求, 从响应头读取额度利用率:
//   anthropic-ratelimit-unified-5h-utilization  (0.0~1.0)
//   anthropic-ratelimit-unified-7d-utilization  (0.0~1.0)
//   anthropic-ratelimit-unified-5h-reset / -7d-reset (unix epoch)
#define CLAUDE_API_HOST   "api.anthropic.com"
#define CLAUDE_API_PATH   "/v1/messages"
#define CLAUDE_PROBE_MODEL "claude-haiku-4-5-20251001"

// ================= Codex (ChatGPT) =================
#define CODEX_USAGE_URL   "https://chatgpt.com/backend-api/wham/usage"
#define OPENAI_TOKEN_URL  "https://auth.openai.com/oauth/token"
// Codex CLI 的公开 OAuth client id (与 ~/.codex/auth.json 配套)
#define CODEX_CLIENT_ID   "app_EMoamEEZ73f0CkXaXp7hrann"
// access token 剩余寿命低于该值时尝试用 refresh token 刷新 (秒)
#define CODEX_REFRESH_MARGIN_S  (24UL * 3600UL)

// ================= 蜂鸣 =================
// 额度重置判定: 利用率相比上次下降超过该百分点, 或 reset 时间戳被跨过
#define RESET_DROP_THRESHOLD  25.0f
#define QUIET_HOUR_START  23   // 静音时段 (本地时间)
#define QUIET_HOUR_END    8

// ================= 时间 =================
#define NTP_SERVER_1  "pool.ntp.org"
#define NTP_SERVER_2  "time.windows.com"
#define TZ_STRING     "CST-8"   // 中国标准时间

// ================= 配网 AP =================
#define AP_SSID_PREFIX  "QuotaTV-"
#define AP_IP           IPAddress(192, 168, 4, 1)

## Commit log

2026-07-15 fix: brand color and case
    [back.stl, body.stl, button_plunger_x2.stl]
2026-07-22 fix: set display brightness to maximum
    [main.cpp]
